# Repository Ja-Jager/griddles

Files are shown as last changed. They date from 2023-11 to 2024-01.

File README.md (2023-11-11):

# ESP-toaster

迁移到 ESP-IDF 平台，增加物联网功能。

死限期：2023 年 2 月 10 日

## 烘包机与炸炉相同功能

| 炸炉 | 烘包机 | 是否能通用 |
| ----- | --- | ----- |
| 温度采集  | 温度采集 | ✔ |
| 继电器 | 继电器 | ✔ |
| 温度判断  | 温度判断 | ✔ |
| 超温保护  | 超温保护 | ✔ |
| 按键 | 按键 | ✔ |
| nvs | nvs | ✔ |
| | 数码管 | ❌ |
| 旋转编码器 | | ❌ |
| 倒计时 | | ❌ |
| | ToF 数面包 | ❌ |

## 完成事项

- [ ] 把当前 Toaster 代码迁移到 Fryer 里
  - [x] 温度采集
  - [x] 继电器
  - [x] 温度判断
  - [x] 超温保护
  - [ ] 按键
- [ ] Fryer 代码
  - [ ] 旋转编码器
  - [x] 倒计时
- [x] 电子板更改设计

## 注意

原本此项是有NTC_thermistor、esp_ntc组件的，但为了队列读取不重复，已经将其压缩放在C盘

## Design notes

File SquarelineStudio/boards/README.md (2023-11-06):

# Custom Boards Usage

The generator supports custom boards. The example of the custom board is [here](https://github.com/espressif/esp-bsp/blob/master/SquareLine/boards/custom_waveshare_7inch). There is custom BSP for the custom board as a component. For use this custom board in SquareLine, follow these steps:

Copy folder from `/espressif/custom_waveshare_7inch` to `"SquareLine Studio installation path"/boards/espressif/`

```
.
├── boards
│   ├── arduino
│   ├── desktop
│   └── espressif
│       ├── custom_waveshare_7inch_v1_0_0
│       │   ├── LICENSE
│       │   ├── custom_waveshare_7inch.png
│       │   ├── custom_waveshare_7inch.slb
│       │   └── custom_waveshare_7inch.zip
│       ├── espbox_v1_0_0
│       └── espwroverkit_v1_0_0

90 directories, 477 files
```

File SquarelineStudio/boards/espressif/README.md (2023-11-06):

# BSP: Custom WaveShare 7inch LCD 

* [Hardware Reference](https://www.waveshare.com/wiki/7inch_Capacitive_Touch_LCD_(C))

This is an example how to make custom BSP and generate custom board for SquareLine Studio.



WaveShare 7inch Capacitive Touch LCD (C) 800x480

* INTERFACE: 8080 series interface
* LCD CONTROLLER: RA8875
* TOUCH CONTROLLER: GT911
* RESOLUTION: 800 * 480 (Pixel)

## Default Hardware Connection

### PARALLEL INTEL 8080 Display

| Display  | ESP32-S3 |
| :---: | :---: |
| CS | **GND**  |
|  RS/DC | GPIO 37  |
| WR | GPIO 38  |
| RD | **3V3**  |
| RST | GPIO 39  |
| PS | **GND**  |
| WAIT |  GPIO 1  |
| D0 | GPIO 13  |
| D1 | GPIO 12  |
| D2 | GPIO 11  |
| D3 | GPIO 10  |
| D4 |  GPIO 9  |
| D5 | GPIO 46  |
| D6 |  GPIO 3  |
| D7 |  GPIO 8  |
| D8 | GPIO 18  |
| D9 | GPIO 17  |
| D10 | GPIO 16  |
| D11 | GPIO 15  |
| D12 |  GPIO 7  |
| D13 |  GPIO 6  |
| D14 |  GPIO 5  |
| D15 |  GPIO 4  |
| D8 ~ D15 | **GND**  |

### I2C Touch

| Display | ESP32-S2 |
| :-----: | :---: |
| SCL | GPIO 41  |
| SDA | GPIO 42  |
| INT |  GPIO 2  |

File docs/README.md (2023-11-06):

# 注意

Header 4 有两个脚接了超温保护。这个电路图没有更新这个事实。

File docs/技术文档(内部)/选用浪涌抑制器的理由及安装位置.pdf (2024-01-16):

# 选用浪涌抑制器的理由及安装位置

选用浪涌抑制器的理由及安装位置
半个扒炉的接线图
具体接线说明
浪涌抑制器
交流接触器
参考实验
实验一
实验二
实验三
实验四
结论
浪涌抑制器的安装位置
结论

## 半个扒炉的接线图

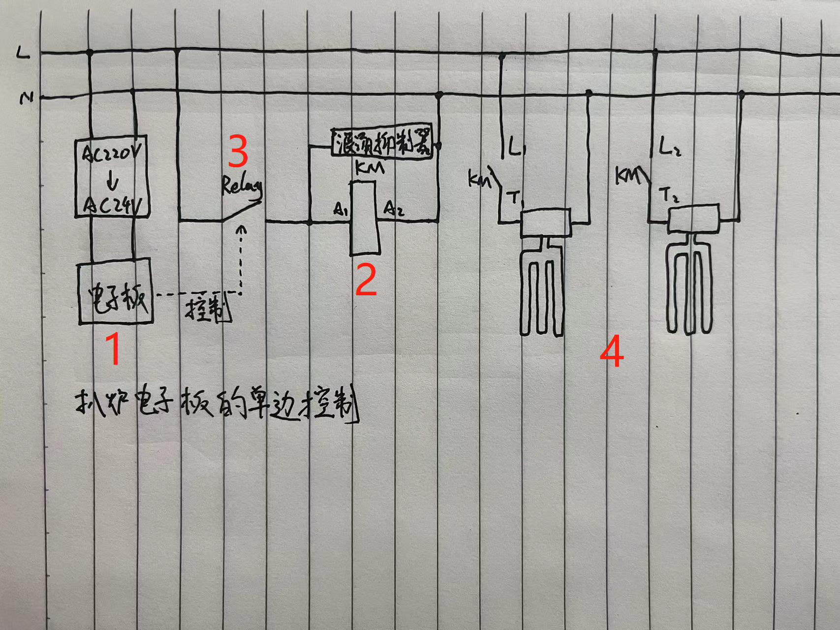
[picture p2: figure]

### 具体接线说明

1. 电子板部分：由一个AC220V转AC24V 80W的变压器供电给电子板。
2. 交流接触器部分：交流接触器控制端有两个引脚A1、A2。

A2直连零线

A1与火线受电子板上的继电器控制导通

A1、A2两端连接浪涌抑制器

3. 电子板继电器控制部分：电子板上的继电器由电子板的硬件设计及加热逻辑所控制。

继电器的控制端由电子板上的24V与达林顿管所控制，只要控制端两端有电压差，继电 器就会吸合

继电器的公共端连接节流接触器的A1脚，常开端连接火线，只要继电器一吸合，交流接 触器的A1脚就等于与火线相连，这样交流接触器就会吸合。

4. 发热管部分：扒炉的一边扒板内部装有两个类似于发热管的加热器件，由交流接触器的输出 端所控制。

交流接触器上除了控制端A1、A2，还有输入端L1、L2、L3、NO，输出端T1、T2、T3、 NO。

输入端L1、L2连接着火线

输出端T1、T2连接着发热管的一端

发热管的另一端直连零线

只要交流继电器吸合，T1、T2等于接通火线，这样发热管就能加热了

## 浪涌抑制器

浪涌抑制器内部主要由电容和电阻的RC电路构成。目的是为了吸收和消耗交流接触器中的电感的 感应电流。

### 交流接触器

在浪涌抑制器的应用之前，先了解交流接触器的组成和造成峰值电流的原因。

1. 交流接触器的组成：交流接触器主要由线圈、衔铁、弹簧、动触点和定触点组成。
2. 交流接触器的工作过程：当交流接触器线圈两端接通火线与零线，线圈就会产生磁场，由楞 次定律，衔铁也会产生磁场，结果线圈与衔铁就吸合在一起。衔铁上连接着动触点，衔铁的 运动使得动触点与常开定触点导通，这样交流接触器就能够正常工作了。
3. 交流接触器的线圈：线圈实际是一段绕成圆筒形的导线，也就是一个电感器件。交流接触器 利用其通电后产生的磁场来控制导通与断开的。但电感最主要的特性还有一个，它能延迟电 流的变化，这会使得线圈在断电后会产生自感电动势。

### 参考实验

可以参考以下博客中所做的实验中的第1至第5点。

继电器线圈泄放电路&&及触点RC吸收电路_接触器线圈吸收电路-CSDN博客 (https://blog.csdn.net/weixin_45633643/article/details/107662100)

这个实验的内容是：通过一个脉冲源控制三极管的通断来模拟继电器（类似接触器）中的线圈的 电压变化；加入反向二极管、RC电路来消除过冲电压。

实验一

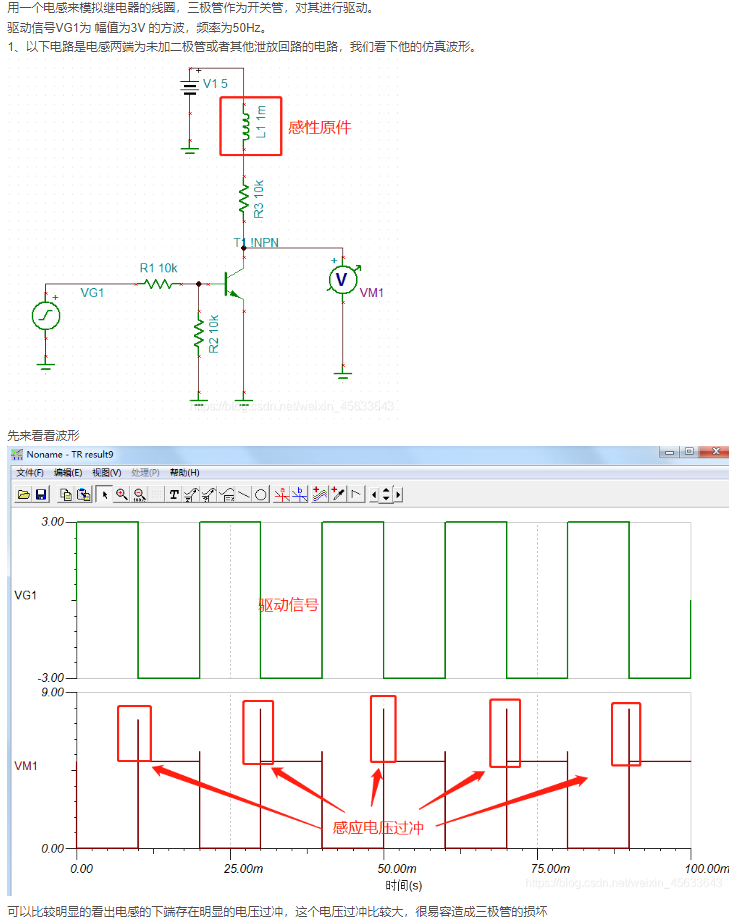
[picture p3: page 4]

实验二

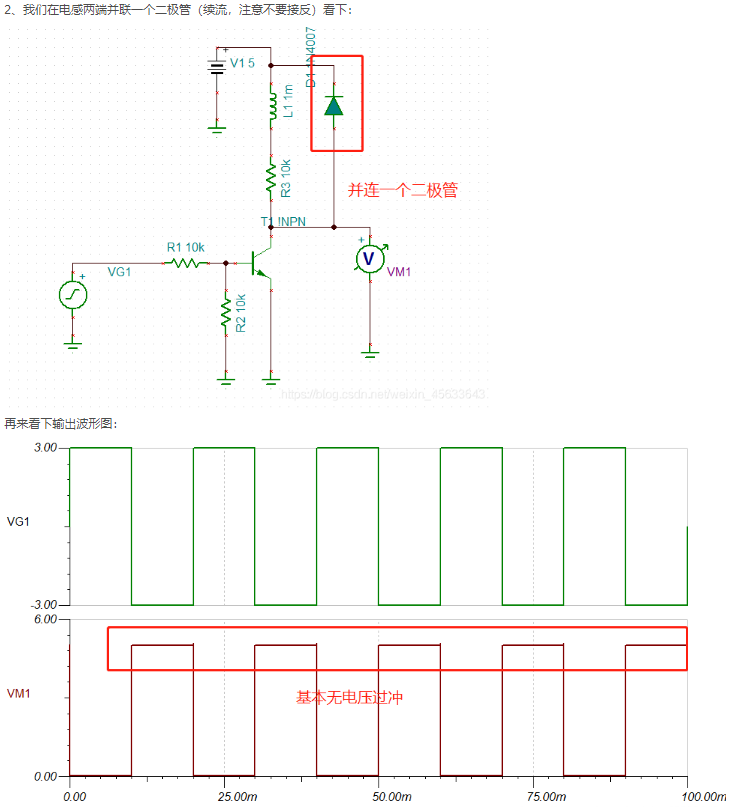
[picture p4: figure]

实验三

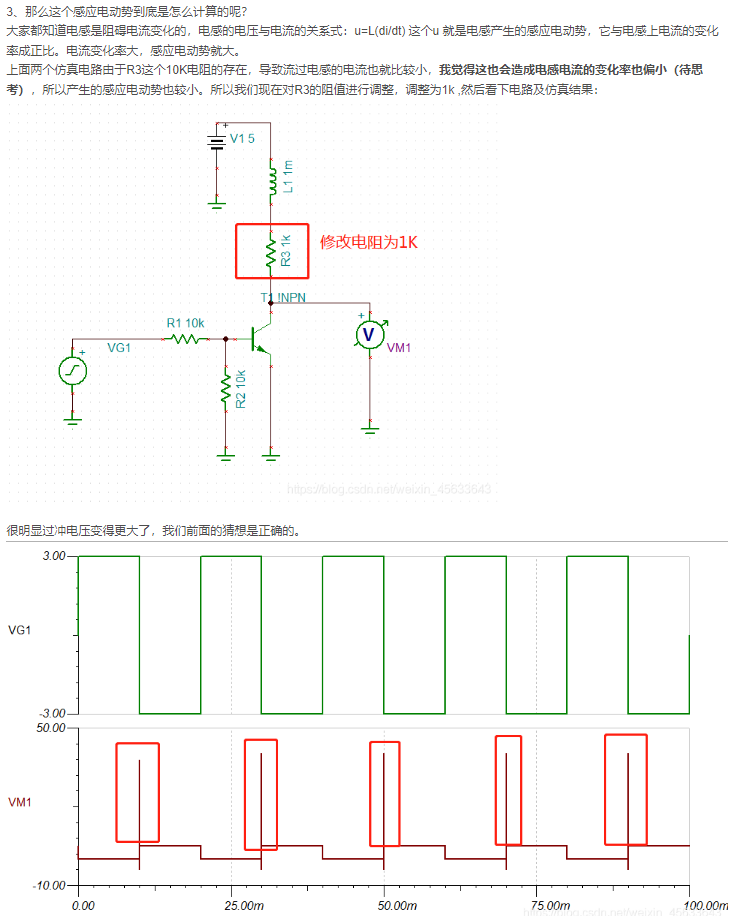
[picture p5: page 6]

实验四

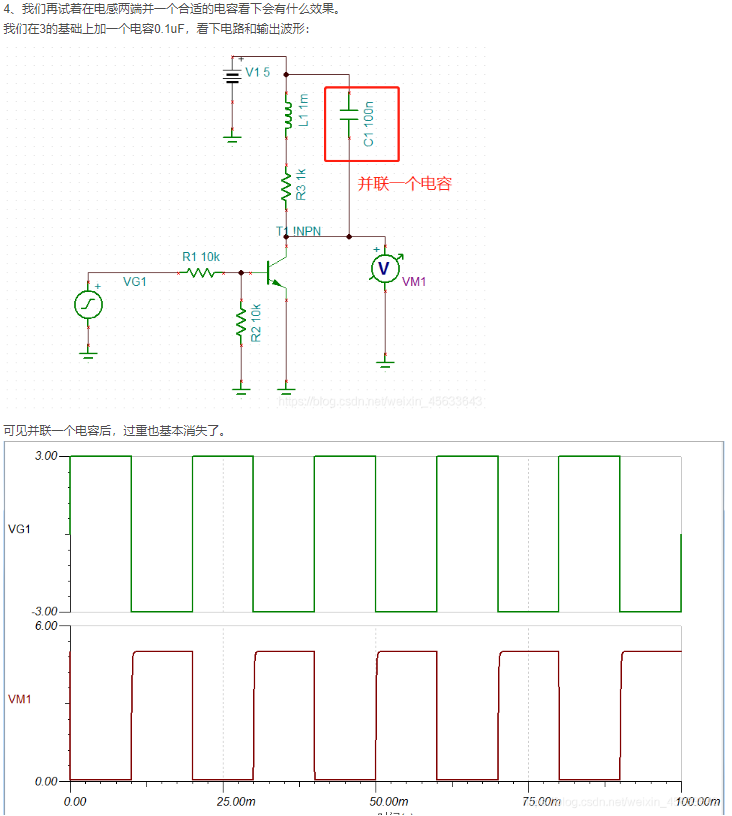
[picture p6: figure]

结论

从以上实验可以看出当电感失去供电后，会出现出现短暂的较大的过冲电压，这对与之相连的电 路会造成较为严重的破坏。

而浪涌抑制器就相当于实验四中加入的电容，可以阻止电压的剧烈变化，再加上个电阻来消耗电 流，故而电路不会再出现电压、电流突然过大的情况。

### 浪涌抑制器的安装位置

浪涌抑制器应安装在交流接触器的线圈两端，也就是A1、A2。
结论

在有线圈需要驱动的强电电路中，安装浪涌抑制器是必要的。

线圈断电后的产生的感应电势、电流会对与之供电相连的其他设备造成破坏，导致一些敏感设备 出现异常。而浪涌抑制器的RC电路能吸收、消耗掉这个感应电势、电流。

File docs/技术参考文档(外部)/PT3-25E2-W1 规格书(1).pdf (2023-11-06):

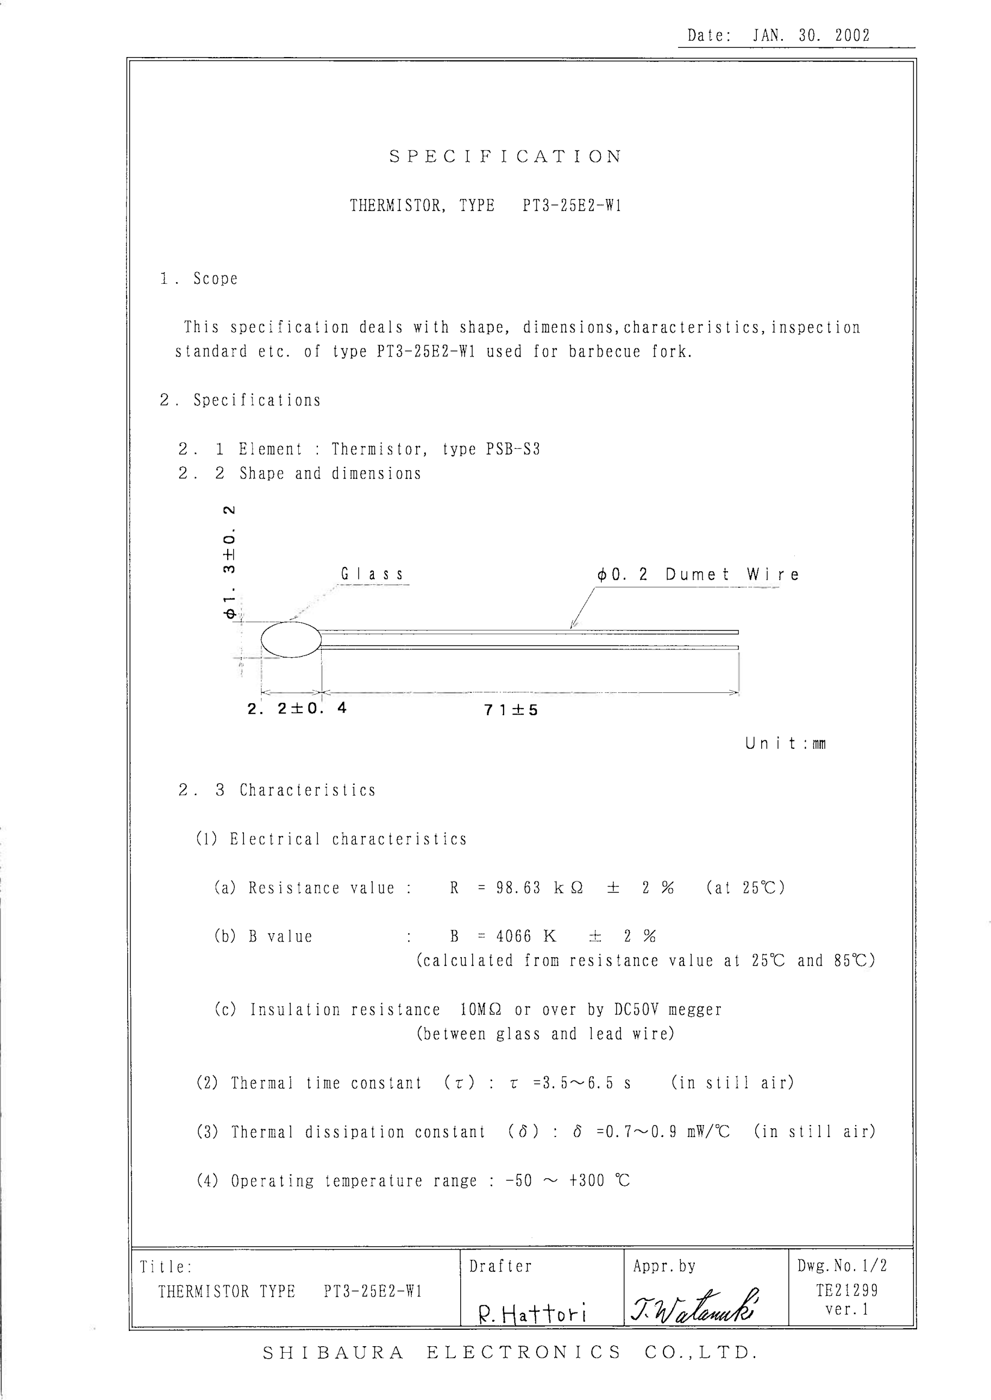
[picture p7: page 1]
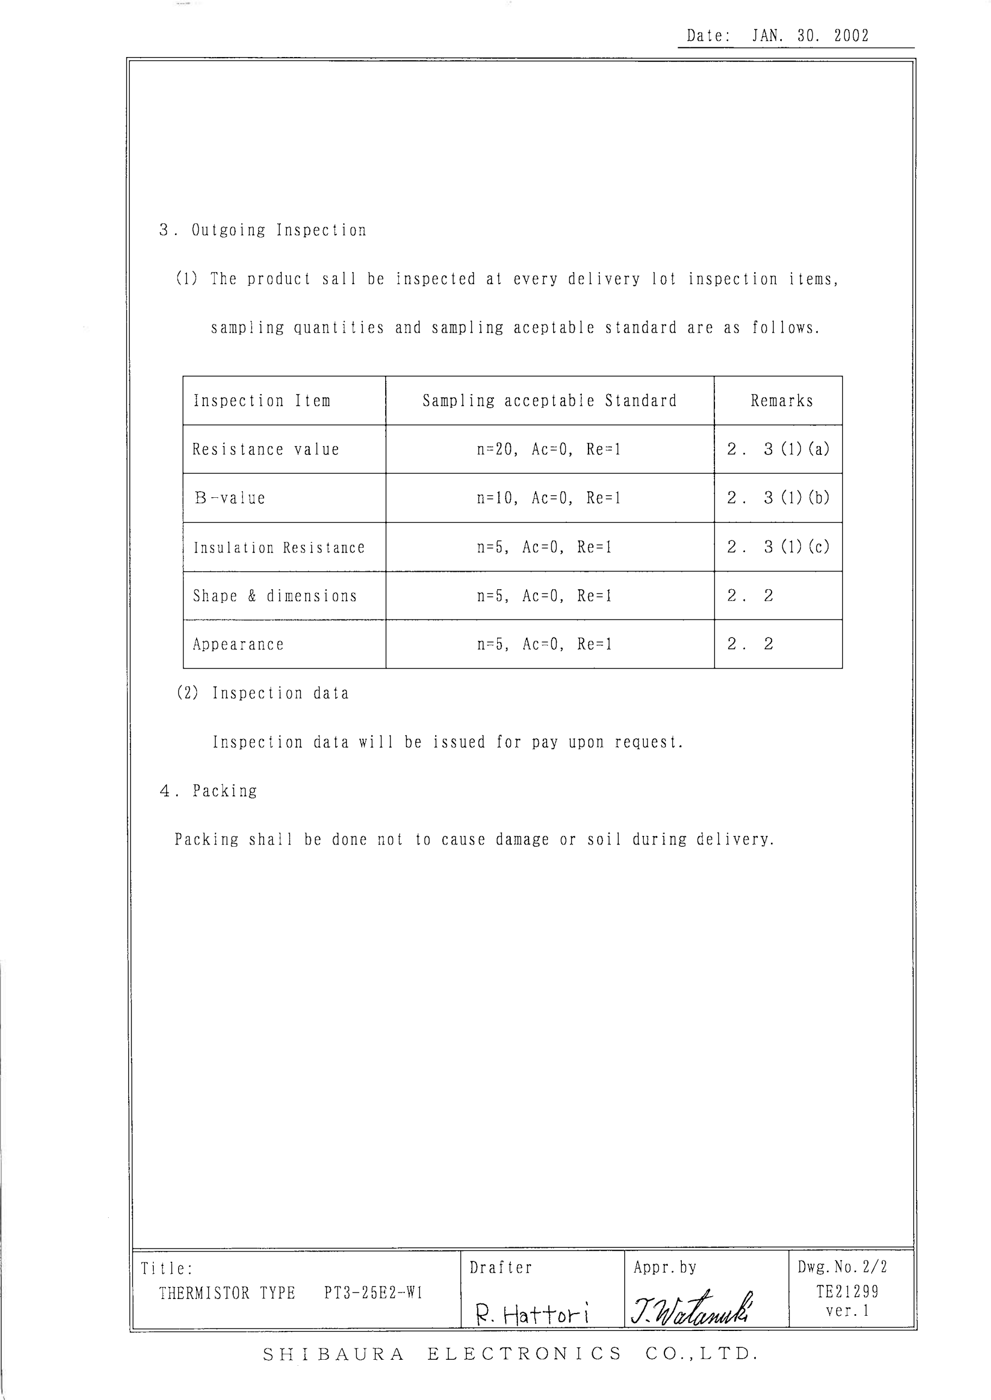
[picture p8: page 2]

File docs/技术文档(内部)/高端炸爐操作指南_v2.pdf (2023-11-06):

# 高端炸爐操作指南

更新时间：2023/9/11 18：00

高端炸爐操作指南
語言切換
使用流程
手動操作
烹飪流程
用戶自定義操作
无倒计时操作
自動操作
烹飪流程
菜單操作
新增菜單
使用流程
編輯菜單
使用流程
刪除菜單
使用流程
溫度單位切換
使用流程
演示模式
使用流程
物理按鍵切換操作頁面
超溫保護、泄油、發熱管擡起

# 語言切換

1. 用戶通過左邊的橫欄【手动】、【计时】、【设置】，按下【设置】以選擇設置。
2. 滑動如下圖的語言切換滾輪。

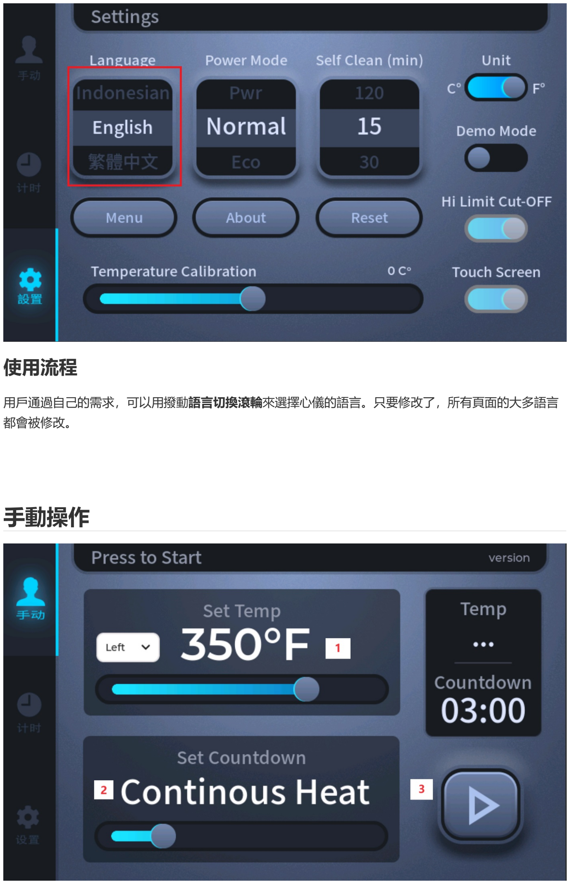
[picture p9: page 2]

## 使用流程

用戶通過自己的需求，可以用撥動語言切換滾輪來選擇心儀的語言。只要修改了，所有頁面的大多語言 都會被修改。

# 手動操作

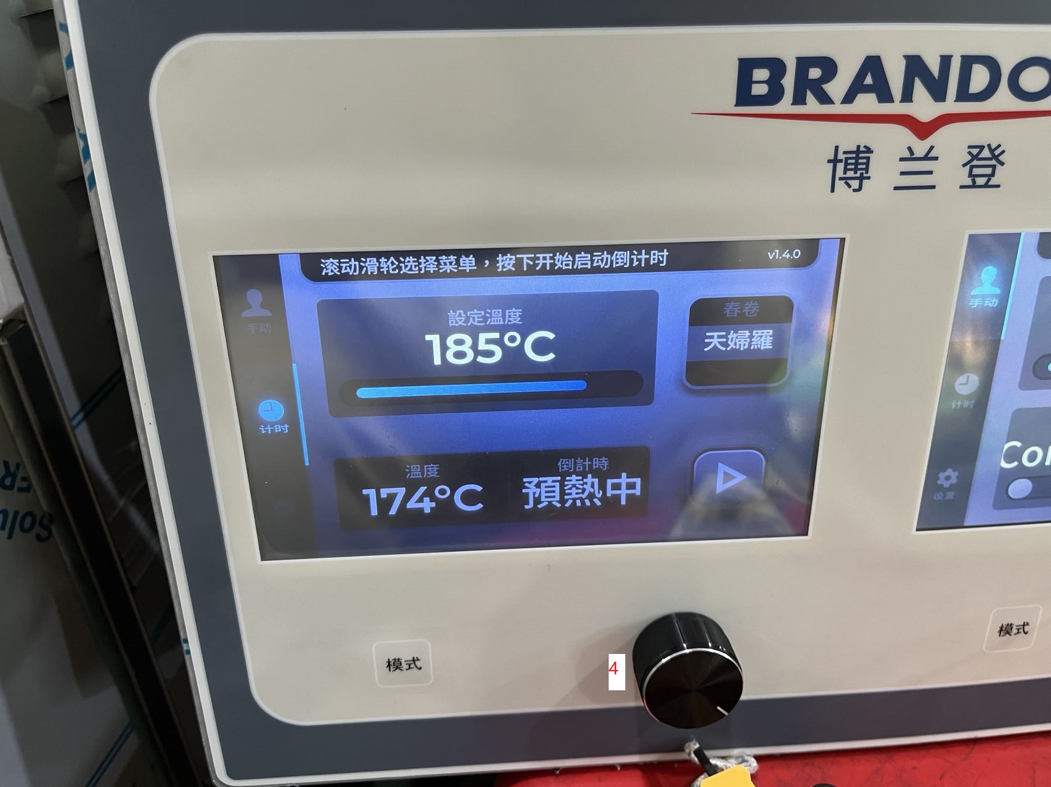
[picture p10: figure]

手動操作可以操作的位置有如上圖的4個位置。

1. 設定溫度滑條（量程：100℃ ~ 200℃，200℉ ~ 400℉）
2. 設定倒計時滑條（量程：15min，滑動的最小一格為10s）
3. 開始鍵
4. 旋鈕及旋鈕按鍵

## 烹飪流程

### 用戶自定義操作

1. 用戶通過左邊的橫欄【手动】、【计时】、【设置】，按下【手动】以選擇手動模式。
2. 用戶通過自己的需求，可以用滑條或旋鈕調整設定溫度。（建議：滑條用於大幅度調整，旋鈕用於 微小調整）。
3. 用戶通過自己的需求，可以用滑條調整設定倒計時。
4. 按下開始鍵或旋鈕，機器就會開啓加熱。
5. 按下開始鍵后，當溫度還未到達設定溫度時，【倒計時】下會顯示【預熱中】。
6. 當溫度達到設定溫度時，會出現一個頁面，提示投放食物。投放完食物后，按下屏幕上的 【DONE】，倒計時開啓。
7. 當倒計時結束或客戶再次按下開始鍵或旋鈕按鍵，機器就會結束倒計時，停止加熱。

### 无倒计时操作

1. 用戶通過自己的需求，可以用滑條或旋鈕調整設定溫度。（建議：滑條用於大幅度調整，旋鈕用於 微小調整）。
2. 當溫度滑條拉至最左端，此時【設定倒計時】下會顯示【持續運行】。
3. 按下開始鍵或旋鈕，機器就會開啓加熱。
4. 按下開始鍵后，當溫度還未到達設定溫度時，【倒計時】下會顯示【預熱中】。
5. 當溫度達到設定溫度時，會出現一個頁面，提示投放食物。投放完食物后，按下屏幕上的 【DONE】。

# 自動操作

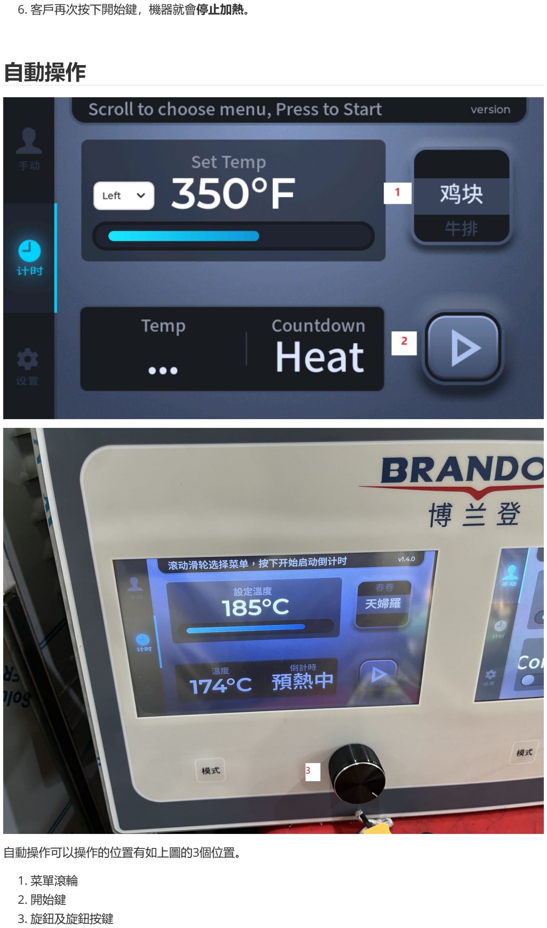
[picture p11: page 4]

6. 客戶再次按下開始鍵，機器就會停止加熱。

自動操作可以操作的位置有如上圖的3個位置。

1. 菜單滾輪
2. 開始鍵
3. 旋鈕及旋鈕按鍵

## 烹飪流程

1. 用戶通過左邊的橫欄【手动】、【计时】、【设置】，按下【自动】以選擇自動模式。
2. 用戶通過自己的需求，可以用滾輪或旋鈕選擇自己想要的菜單。
3. 按下開始鍵或旋鈕，機器就會開啓加熱。
4. 按下開始鍵后，當溫度還未到達設定溫度時，【倒計時】下會顯示【預熱中】。
5. 當溫度達到設定溫度時，會出現一個頁面，提示投放食物。投放完食物后，按下屏幕上的 【DONE】，倒計時開啓。
6. 客戶再次按下開始鍵，機器就會停止加熱。
7. 當用戶用自動模式開啓加熱時，如果沒有切換界面，按下任何物理按鍵、開始鍵和滑動滾輪，就會 彈出一個屏保頁面，類似與下圖。顯示的内容：倒計時、菜單名。

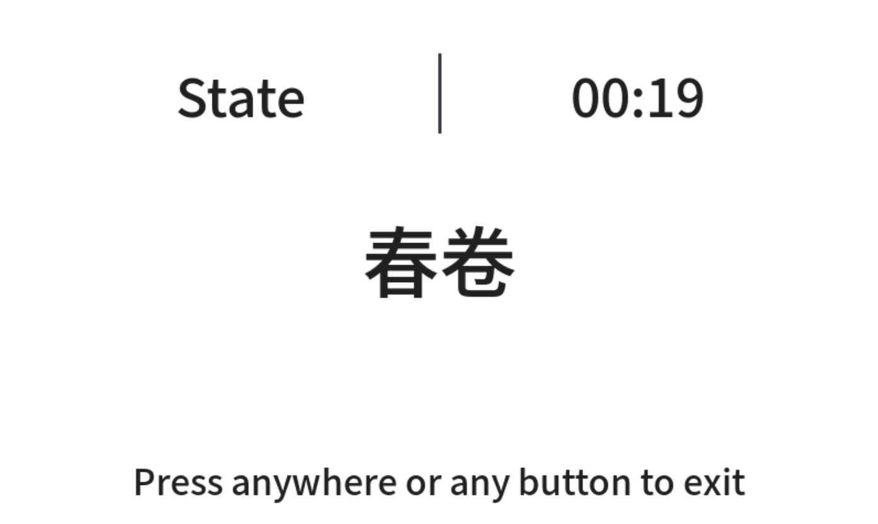
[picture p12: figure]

# 菜單操作

1. 用戶通過左邊的橫欄【手动】、【计时】、【设置】，按下【设置】以選擇設置。
2. 點擊如下圖的【menu】。

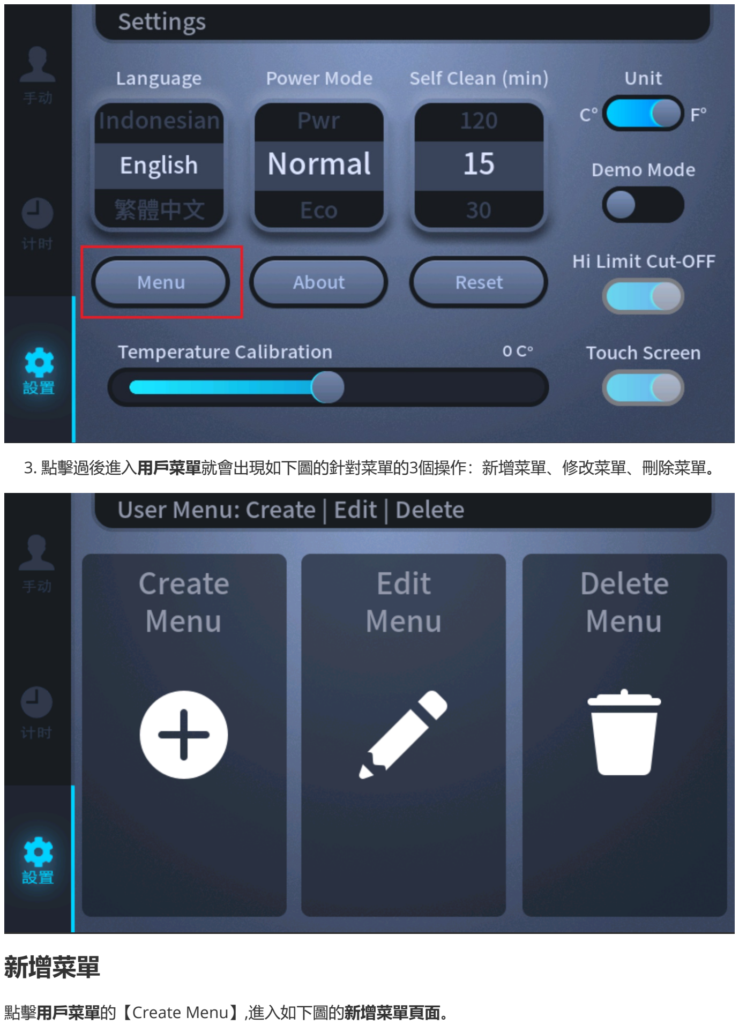
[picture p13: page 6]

3. 點擊過後進入用戶菜單就會出現如下圖的針對菜單的3個操作：新增菜單、修改菜單、刪除菜單。

## 新增菜單

點擊用戶菜單的【Create Menu】,進入如下圖的新增菜單頁面。

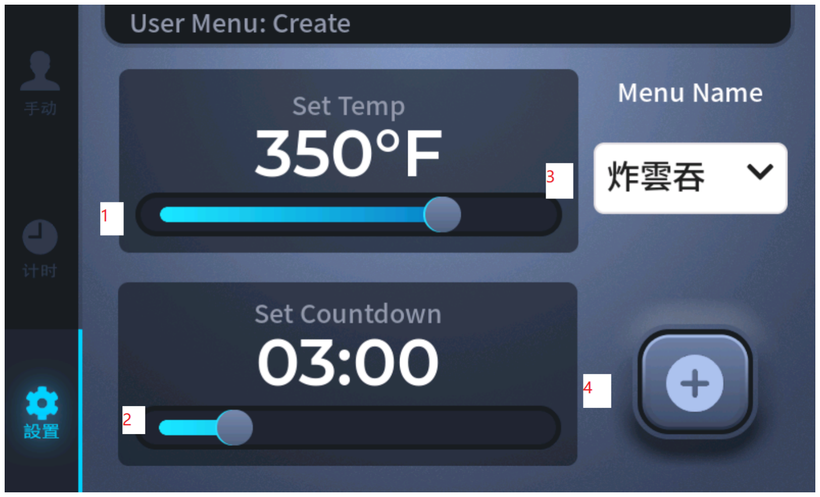
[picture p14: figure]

新增菜單可以操作的位置有如上圖的4個位置。

1. 設定溫度滑條（量程：100℃ ~ 200℃，200℉ ~ 400℉）
2. 設定倒計時滑條（量程：15min，滑動的最小一格為10s）
3. 菜單列表
4. 新增菜單鍵

### 使用流程

1. 用戶通過自己的需求，可以用滑條調整設定溫度。
2. 用戶通過自己的需求，可以用滑條調整設定倒計時。
3. 用戶通過自己的需求，可以用下拉式列表選擇心儀的菜單名。
4. 用戶確定完自己的選擇後，通過按下新增菜單鍵來新增菜單，新增的菜單出現將在自動操作的滾輪 選項中。

## 編輯菜單

點擊用戶菜單的【Edit Menu】,進入如下圖的編輯菜單頁面1。

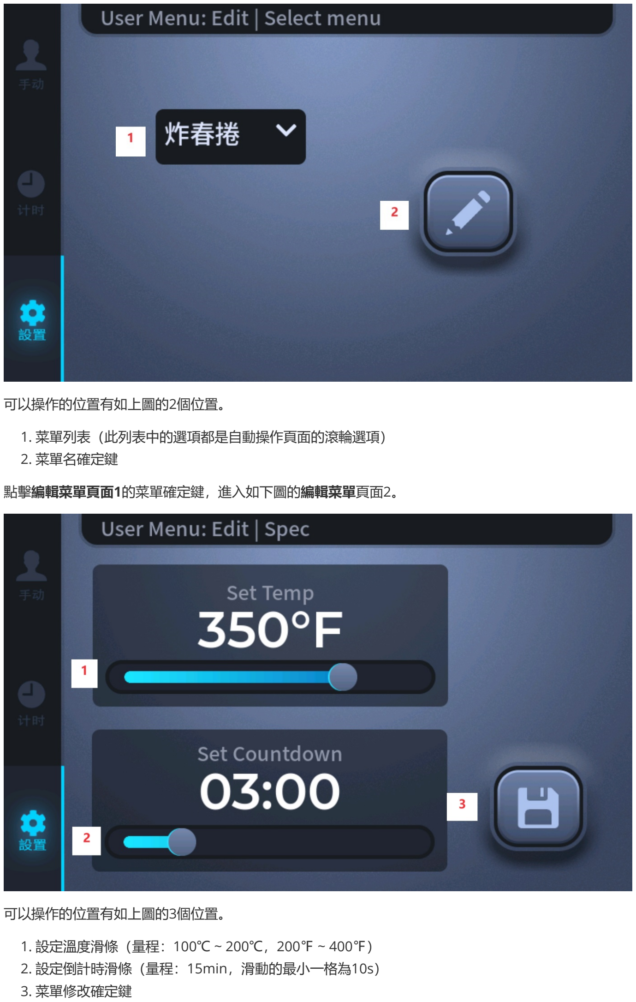
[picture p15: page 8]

可以操作的位置有如上圖的2個位置。

1. 菜單列表（此列表中的選項都是自動操作頁面的滾輪選項）
2. 菜單名確定鍵

點擊編輯菜單頁面1的菜單確定鍵，進入如下圖的編輯菜單頁面2。

可以操作的位置有如上圖的3個位置。

1. 設定溫度滑條（量程：100℃ ~ 200℃，200℉ ~ 400℉）
2. 設定倒計時滑條（量程：15min，滑動的最小一格為10s）
3. 菜單修改確定鍵

### 使用流程

1. 用戶通過自己的需求，可以用菜單列表選擇需要修改的自動操作頁面的菜單選項。
2. 按下菜單名確定鍵，進入編輯菜單頁面2。
3. 進入編輯菜單頁面2后，用戶通過自己的需求，可以用滑條修改設定溫度。
4. 用戶通過自己的需求，可以用滑條修改設定倒計時。
5. 用戶確定完自己的要修改的選擇後，通過按下菜單修改確定鍵來修改菜單，修改后的菜單會更新到 自動操作的滾輪選項中。

## 刪除菜單

點擊用戶菜單的【Delete Menu】,進入如下圖的刪除菜單頁面。

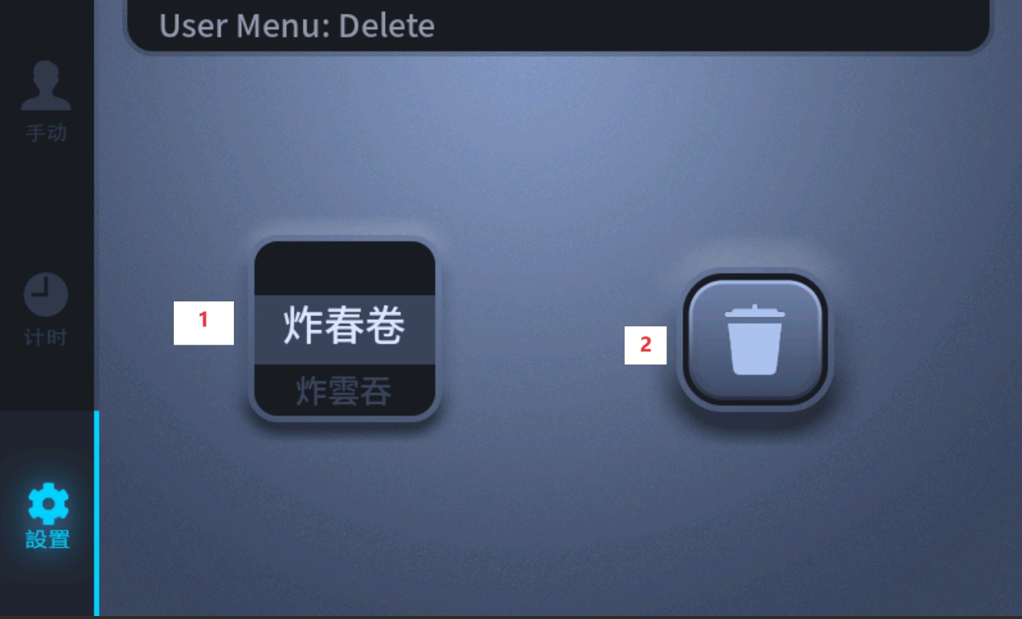
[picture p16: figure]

可以操作的位置有如上圖的2個位置。

1. 菜單名滾輪（此列表中的選項都是自動操作頁面的滾輪選項）
2. 菜單刪除確定鍵

### 使用流程

1. 用戶通過自己的需求，可以用菜單名滾輪選擇需要刪除的自動操作頁面的菜單選項。
2. 用戶確定完自己的要刪除的選擇後，通過按下菜單刪除確定鍵來刪除菜單，刪除后，菜單會更新到 自動操作的滾輪選項中。

# 溫度單位切換

1. 用戶通過左邊的橫欄【手动】、【计时】、【设置】，按下【设置】以選擇設置。
2. 點擊如下圖的溫度單位切換開關。

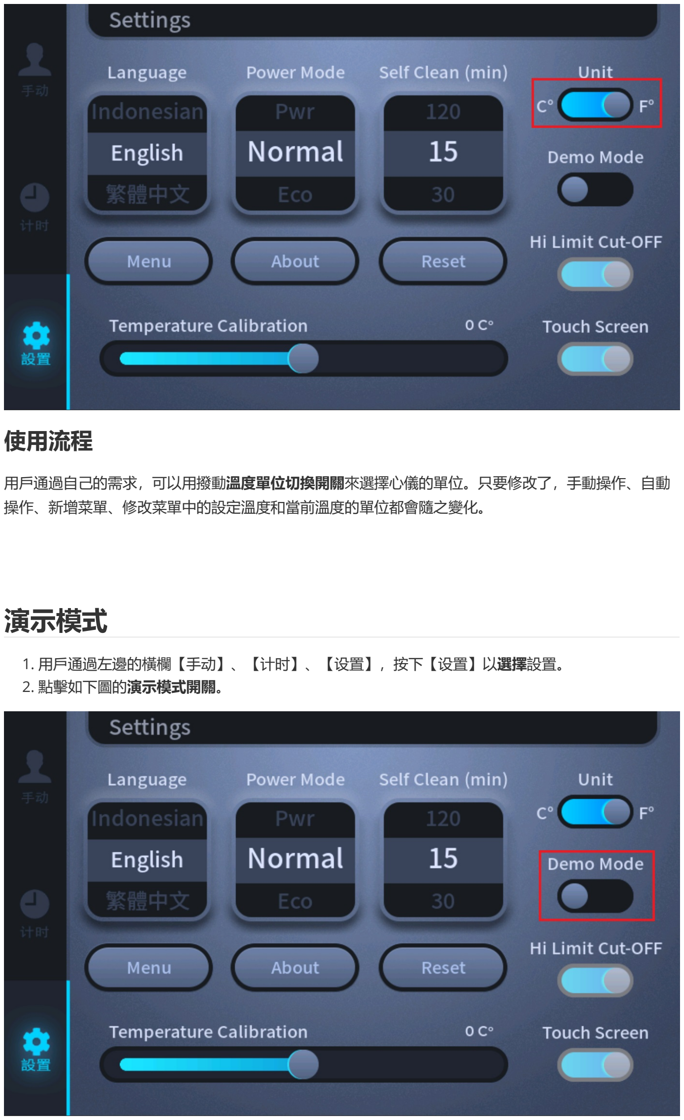
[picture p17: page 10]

## 使用流程

用戶通過自己的需求，可以用撥動溫度單位切換開關來選擇心儀的單位。只要修改了，手動操作、自動 操作、新增菜單、修改菜單中的設定溫度和當前溫度的單位都會隨之變化。

# 演示模式

1. 用戶通過左邊的橫欄【手动】、【计时】、【设置】，按下【设置】以選擇設置。
2. 點擊如下圖的演示模式開關。

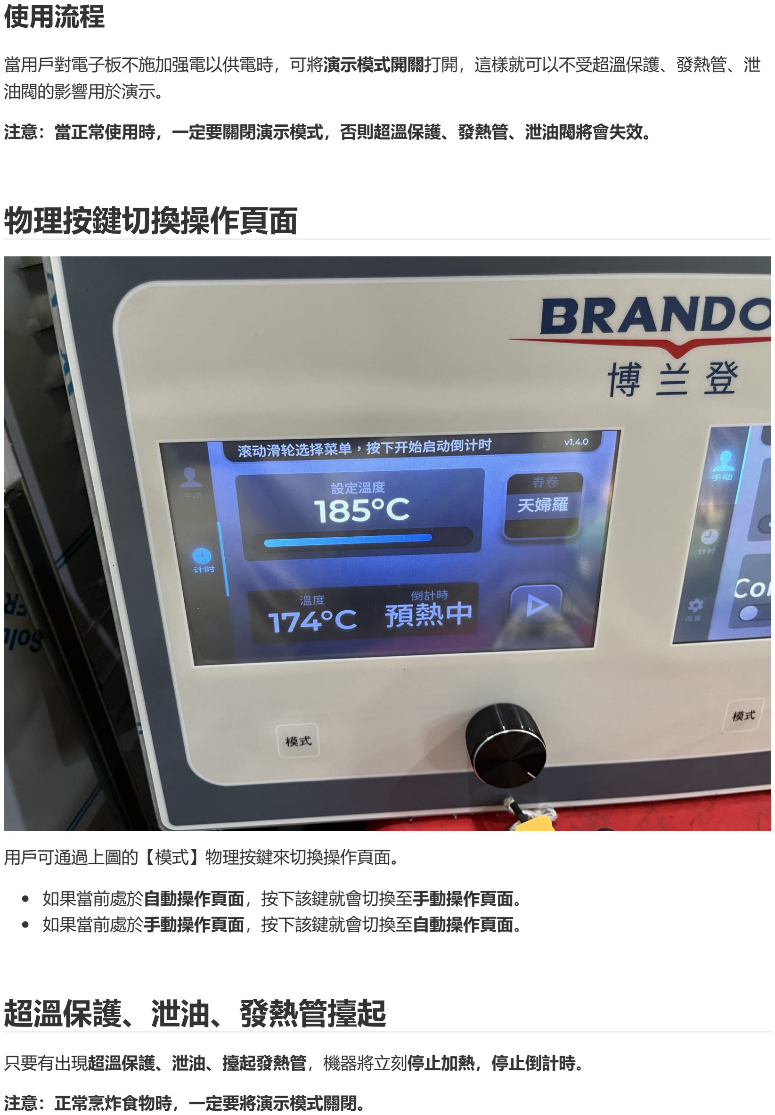
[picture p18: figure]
使用流程; 當用戶對電子板不施加强電以供電時，可將演示模式開關打開，這樣就可以不受超溫保護、發熱管、泄 油閥的影響用於演示。; 注意：當正常使用時，一定要關閉演示模式，否則超溫保護、發熱管、泄油閥將會失效。; 物理按鍵切換操作頁面; 用戶可通過上圖的【模式】物理按鍵來切換操作頁面。; 如果當前處於自動操作頁面，按下該鍵就會切換至手動操作頁面。 如果當前處於手動操作頁面，按下該鍵就會切換至自動操作頁面。; 超溫保護、泄油、發熱管擡起; 只要有出現超溫保護、泄油、擡起發熱管，機器將立刻停止加熱，停止倒計時。; 注意：正常烹炸食物時，一定要將演示模式關閉。

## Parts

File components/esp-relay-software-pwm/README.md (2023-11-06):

# ESP-RELAY-SOFTWARE-PWM

1. 声明一个结构体配置初始化参数并初始化

``` c
softPwm_t softpwm=
{
    .PWMPin = 19,
    .freq = 0.2,
};

```

2. 调用 softpwm_init(&softpwm)

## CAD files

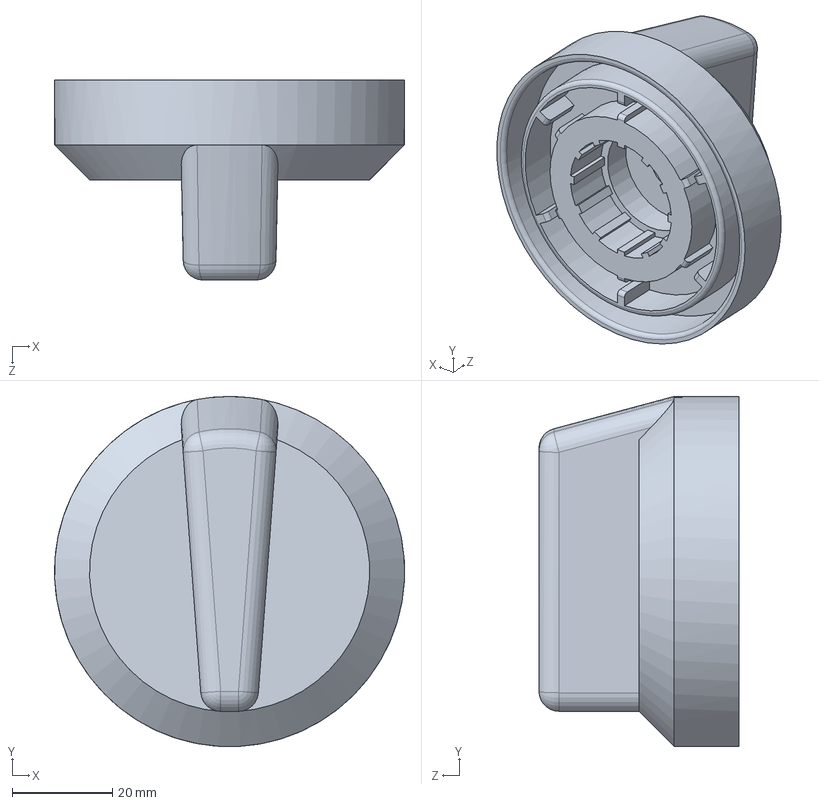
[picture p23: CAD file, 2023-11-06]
docs/技术文档(内部)/旋钮7.0.SLDPRT
70.0 x 70.0 x 40.0 mm

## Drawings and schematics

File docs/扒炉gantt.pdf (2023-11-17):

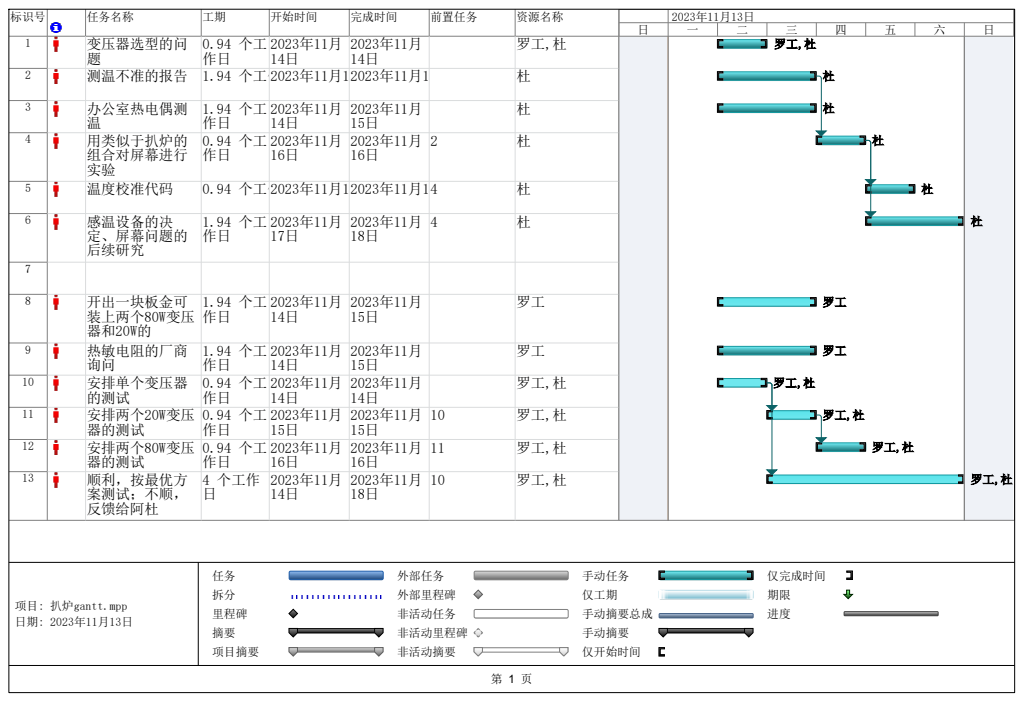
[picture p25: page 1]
标识号; 任务名称; 开始时间; 完成时间; 前置任务; 资源名称; 变压器选型的问; 测温不准的报告; 1.94 个工作日2023年11月14日2023年11月15日; 办公室热电偶测; 用类似于扒炉的; 组合对屏幕进行 实验; 温度校准代码; 0.94 个工作日2023年11月17日2023年11月17日4; 感温设备的决; 定、屏幕问题的 后续研究; 开出一块板金可; 装上两个80W变压 器和20W的; 热敏电阻的厂商; 安排单个变压器; 的测试; 安排两个20W变压; 器的测试; 安排两个80W变压; 顺利，按最优方; 案测试；不顺， 反馈给阿杜; 4 个工作 日; 里程碑; 项目摘要; 外部任务; 外部里程碑; 非活动任务; 非活动里程碑; 非活动摘要; 手动任务; 仅工期; 手动摘要总成; 手动摘要; 仅开始时间; 仅完成时间

项目: 扒炉gantt.mpp

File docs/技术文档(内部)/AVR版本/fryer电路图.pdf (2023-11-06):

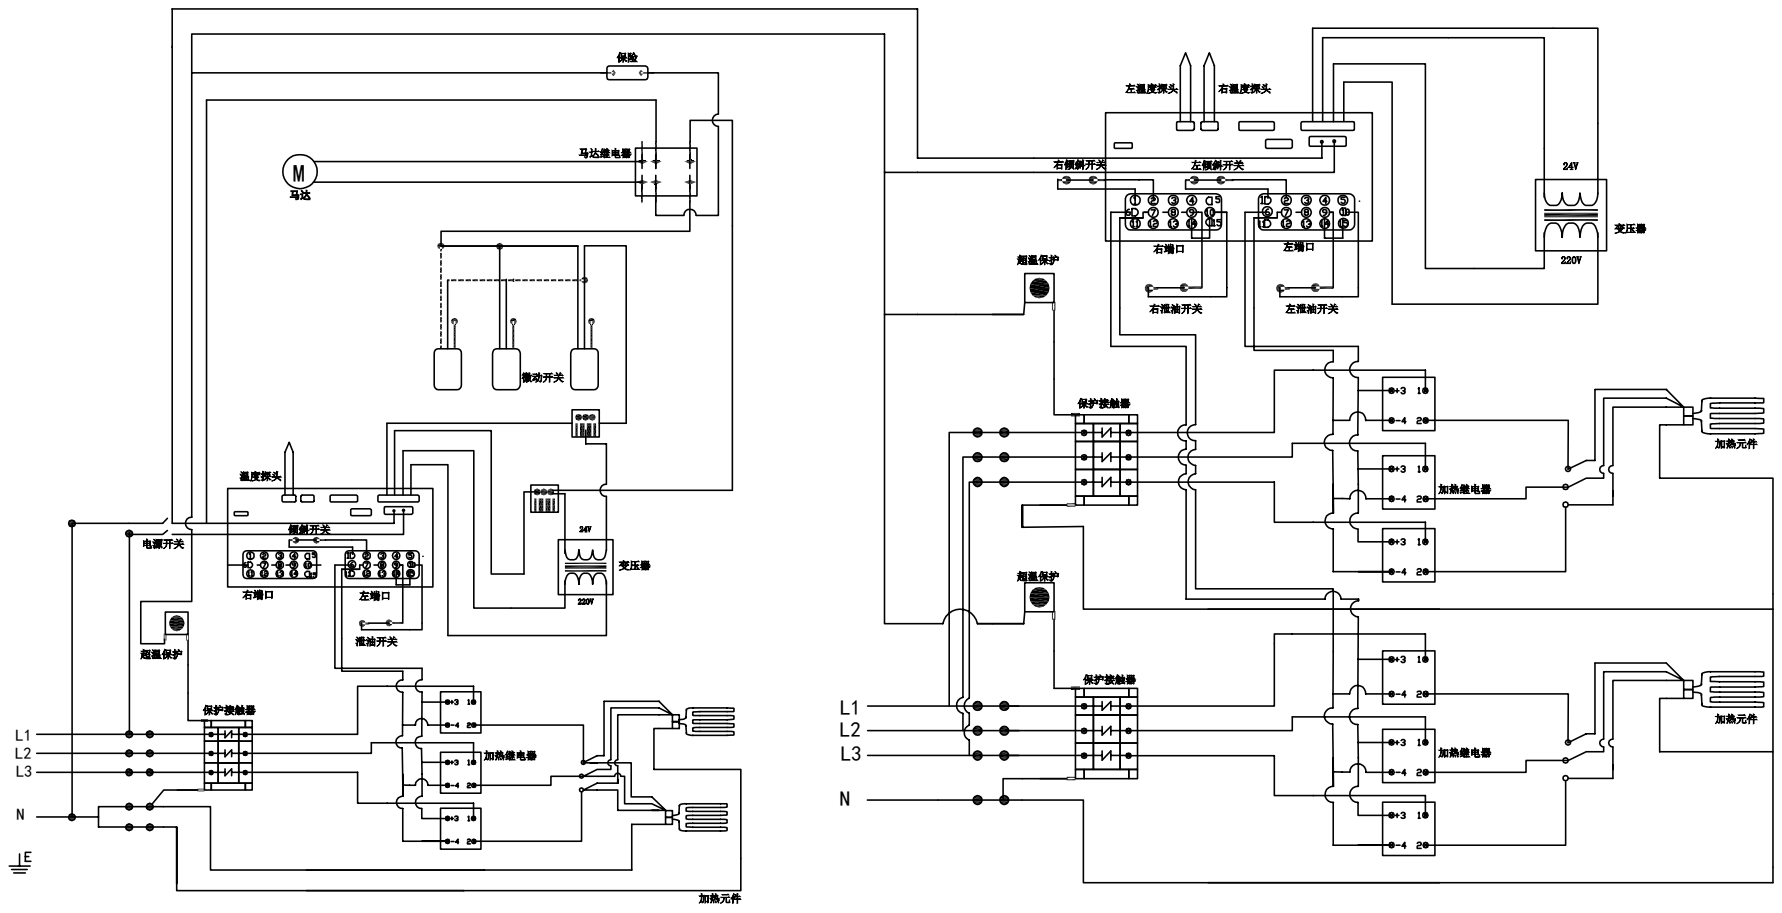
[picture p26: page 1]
泄油开关; 倾斜开关; 右端口; 保护接触器; 电源开关; 加热元件; 加热继电器; 马达继电器; 温度探头; 变压器; 超温保护; 微动开关; 左端口; 右倾斜开关; 左倾斜开关; 右泄油开关; 左泄油开关; 左温度探头; 右温度探头

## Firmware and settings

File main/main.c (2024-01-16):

#include "main.h"

#define TAG "ESP-EXAMPLE"

#define Manual_Temperature_Fahrenheit_Maximum 464
#define Manual_Temperature_Fahrenheit_Minimum 212

#define Manual_Temperature_Celsius_Maximum 240
#define Manual_Temperature_Celsius_Minimum 100

#define Temperature_Unit_Fahrenheit_for_main 1
#define Temperature_Unit_Celsius_for_main 0

#define Time_Needed_appear_ScreenSaver 30

lv_obj_t *label;

bool temperature_unit_main = Temperature_Unit_Fahrenheit_for_main;

screen_is_loaded_t current_screen_load = No_loaded;
// TaskHandle_t * handle_UI_Task;

/*******************************************************************************
 * Private functions
 *******************************************************************************/
void UI_task(void *pvParameters)
{
    // 上电读取NVS，修改语言
    set_language_by_nvs_for_power_on();

    // 自动操作初始化显示
    food_menu_item_config temporary_menu = menu_search_by_sequence(0); // 选择默认鸡块菜单
    double TargetTemperature = 450;

    // lv_obj_add_flag(ui_DropdownMotorLeftRightAuto, LV_OBJ_FLAG_HIDDEN);     /// Flags
    // lv_obj_add_flag(ui_DropdownMotorLeftRightManual, LV_OBJ_FLAG_HIDDEN);     /// Flags

    if (temperature_unit == Temperature_Unit_Fahrenheit)
    {
        Encoder_temperature_queue_write(((TargetTemperature - 273.15) * 1.80 + 32.00));
    }
    else
    {
        Encoder_temperature_queue_write((TargetTemperature - 273.15));
    }
    int32_t current_encoder = 0;
    int32_t previous_encoder = 0;

    // 显示初始化自動操作倒计时
    lv_label_set_text_fmt(ui_LabelSetTimeValue, _("%d:%d"), temporary_menu.cooking_timer_seconds / 60, temporary_menu.cooking_timer_seconds % 60); // 显示初始设定时间

    // 显示初始化手動操作倒计时
    lv_label_set_text_fmt(ui_LabelSensorTempValue2, "%s", _("03:00"));

    // 显示初始化手動操作设定时间
    lv_label_set_text(ui_LabelManualTimerSet, "03:00");

    // 显示初始化温度
    if (temperature_unit == Temperature_Unit_Fahrenheit_for_main)
    {
        lv_label_set_text_fmt(ui_LabelTargetTemperatureValue, "%d°F", (int32_t)(round)((temporary_menu.target_temperature - 273.15) * 1.80 + 32.00)); // 显示初始设定温度
    }
    else
    {
        lv_label_set_text_fmt(ui_LabelTargetTemperatureValue, "%d°C", (int32_t)(round)(temporary_menu.target_temperature - 273.15)); // 显示初始设定温度
    }

    // 显示版本号
    lv_label_set_text_fmt(ui_LabelHeaderVersionNumber, "%s", VERSION_NUMBER);
    lv_label_set_text_fmt(ui_LabelHeaderVersionNumber1, "%s", VERSION_NUMBER);

    /* 提取menu_config_json_str菜单名并写入 */
    cJSON *menu_config_json;
    menu_config_json = cJSON_Parse(menu_config_json_str_return());

    cJSON *food_menu = cJSON_GetObjectItemCaseSensitive(menu_config_json, "food_menu");
    int array_size = cJSON_GetArraySize(food_menu);

    char menu_roller_new_option_name[500] = "";
    for (int i = 0; i < array_size; i++)
    {
        cJSON *food = cJSON_GetArrayItem(food_menu, i);
        cJSON *food_name = cJSON_GetObjectItemCaseSensitive(food, "name");
        if (i == 0)
        {
            strcpy(menu_roller_new_option_name, food_name->valuestring);
        }
        else
        {
            strcat(menu_roller_new_option_name, "\n");
            strcat(menu_roller_new_option_name, food_name->valuestring);
        }
    }
    cJSON_Delete(menu_config_json);
    lv_roller_set_options(ui_MenuOptionRollerChoose, menu_roller_new_option_name, LV_ROLLER_MODE_NORMAL);
    lv_roller_set_options(ui_RollerDeleteMenuChoose, menu_roller_new_option_name, LV_ROLLER_MODE_NORMAL);
    lv_dropdown_set_options(ui_DropdownEditMenuChoose, menu_roller_new_option_name);
    /* Create a task for NTC thermistor */
    lv_timer_t *timer_thermistor_update = lv_timer_create(NTC_thermistor_update_UI, 100, NULL);

    /* Create a task for manual countdown */
    lv_timer_t *manual_countdown_update = lv_timer_create(manual_mode_countdown_update_UI, 100, NULL);

    /* 当前屏幕 */
    lv_obj_t *active_screen;
    uint16_t MenuRollerChooseSelectedOption = 0;

    // printf("Calibration: %d\n", NTC_thermistor_calibration_queue_read());
    lv_label_set_text_fmt(ui_Label_Print_Speed_Number, "%d K", NTC_thermistor_calibration_queue_read());
    lv_slider_set_value(ui_Slider_Print_Speed, NTC_thermistor_calibration_queue_read(), LV_ANIM_OFF);

    lv_obj_add_event_cb(ui_ScreenAuto, my_ScreenAuto_cb, LV_EVENT_ALL, NULL);
    lv_obj_add_event_cb(ui_ScreenManual, my_ScreenManual_cb, LV_EVENT_ALL, NULL);
    lv_obj_add_event_cb(ui_ScreenSetting, my_ScreenSetting_cb, LV_EVENT_ALL, NULL);
    while (1) 
    {     
        // Manual Mode
        // 手动操作倒计时剩余时间显示
        enum mode_select_state current_PID_mode = PID_mode_read();

        lv_label_set_text(ui_LabelAutoHeader, "Scroll to choose menu, Press to Start");//"滚动滑轮选择菜单，按下开始键启动倒计时"
        lv_label_set_text(ui_LabelAutoHeader1, "Press Start to turn on cooking.");//"按下开始键保持恒温"

        // 手动操作温度显示（旋钮）
        current_encoder = Encoder_queue_read();
        TargetTemperature = Encoder_temperature_queue_read();
        //获取屏幕名称
        
        if (current_encoder != previous_encoder)
        {
            active_screen = lv_scr_act();
            if((active_screen == ui_ScreenAuto) || (active_screen == ui_ScreenScreenSaverMenu))
            {
                if(lv_roller_get_selected(ui_MenuOptionRollerChoose) == 0)
                {
                    if((current_encoder - previous_encoder) < 0)
                    {
                        MenuRollerChooseSelectedOption = 0;
                    }
                    else
                    {
                        MenuRollerChooseSelectedOption = lv_roller_get_selected(ui_MenuOptionRollerChoose) + (current_encoder - previous_encoder);
                    }
                }
                else
                {
                    MenuRollerChooseSelectedOption = lv_roller_get_selected(ui_MenuOptionRollerChoose) + (current_encoder - previous_encoder);
                }
                lv_roller_set_selected(ui_MenuOptionRollerChoose, MenuRollerChooseSelectedOption, LV_ANIM_ON);
                vTaskDelay(1 / portTICK_PERIOD_MS);
                lv_event_send(ui_MenuOptionRollerChoose, LV_EVENT_VALUE_CHANGED, NULL);
            }
            else if(active_screen == ui_ScreenManual)
            {
                TargetTemperature = TargetTemperature + (double)(current_encoder - previous_encoder);
                if (temperature_unit == Temperature_Unit_Fahrenheit_for_main)
                {
                    if (TargetTemperature >= Manual_Temperature_Fahrenheit_Maximum)
                    {
                        TargetTemperature = Manual_Temperature_Fahrenheit_Maximum;
                    }
                    else if (TargetTemperature <= Manual_Temperature_Fahrenheit_Minimum)
                    {
                        TargetTemperature = Manual_Temperature_Fahrenheit_Minimum;
                    }
                }
                else
                {
                    if (TargetTemperature >= Manual_Temperature_Celsius_Maximum)
                    {
                        TargetTemperature = Manual_Temperature_Celsius_Maximum;
                    }
                    else if (TargetTemperature <= Manual_Temperature_Celsius_Minimum)
                    {
                        TargetTemperature = Manual_Temperature_Celsius_Minimum;
                    }
                }
            }  
        }
        // printf("TargetTemperature:\n%f\n", TargetTemperature);
        if (temperature_unit == Temperature_Unit_Fahrenheit_for_main)
        {
            lv_label_set_text_fmt(ui_LabelManualTargetTemperature, "%d°F", (int32_t)TargetTemperature);
        }
        else
        {
            lv_label_set_text_fmt(ui_LabelManualTargetTemperature, "%d°C", (int32_t)TargetTemperature);
        }
        lv_slider_set_value(ui_SliderManualTargetTemperature, (int32_t)TargetTemperature, LV_ANIM_ON);

        Encoder_temperature_queue_write(TargetTemperature);
        previous_encoder = current_encoder;

        if (current_PID_mode == mode_manual)
        {
            if (temperature_unit == Temperature_Unit_Fahrenheit_for_main)
            {
                PID_set_temperature_write((TargetTemperature - 32.00) / 1.800 + 273.15); // 发送手动操作设定温度给PID
            }
            else
            {
                PID_set_temperature_write(TargetTemperature + 273.15); // 发送手动操作设定温度给PID
            }
        }
        // printf("current_PID_mode:%d\n", current_PID_mode);
        vTaskDelay(150 / portTICK_PERIOD_MS);
    }
}

// *INDENT-OFF*
void app_lvgl_display(void)
{
    bsp_display_lock(0);

#ifdef LVGL_BENCHMARK
    lv_demo_benchmark();
#else
    ui_init();
#endif

    bsp_display_unlock();
}

void app_main(void)
{
    nvs_init();

    encoder_queue_init();

    // liftTube_spillOil_overHeat_init();
    /* Test menu read NVS when first power on */
    // menu_test_for_first_power_on("food_menu_nvs");

    // /* Initialize NTC_thermistor */
    // NTC_thermistor_init();
    Max6675_init();

    // /* Initialize PID calculate */
    PID_calculate_init();

    /* Initialize buzzer */
    buzzer_init();
    // buzzer(NOTE_G4, 0, 0, 0, 0);

    /* Initialize timer mode */
    countdown_init();

    /* Initialize manual mode */
    manual_mode_init();

    // /* Initialize PWM */
    softPwm_t softpwm =
        {
            .PWMPin = 4,
            .freq = 0.2,
        };
    softpwm_init(&softpwm);

    /* Initialize I2C (for touch) */
    bsp_i2c_init();
    /* Initialize display and LVGL */
    bsp_display_start();
    // bsp_display_rotate(bsp_display_start(), LV_DISP_ROT_180);

    /* Turn on display backlight */
    bsp_display_backlight_on();

    /* Add and show objects on display */
    app_lvgl_display();

    // xTaskCreate(memory_monitor_task, "memory_monitor_task", 1024 * 4, NULL, 2, NULL);

    // input_task_create();

#ifndef LVGL_BENCHMARK
    xTaskCreate(UI_task, "UI_task", 1024 * 16, NULL, 2, NULL);
    lv_init();
    lv_port_indev_init();
#endif
    ESP_LOGI(TAG, "Example initialization done.");
}
// *INDENT-ON*

void memory_monitor_task(void *pvParameters)
{
    uint32_t total, used, largest, free_heap;
    while (1)
    {
        total = getHeapSize();
        ESP_LOGI("HEAP INFO", "used heap:%ld", total);

        used = total - xPortGetFreeHeapSize();
        ESP_LOGI("HEAP INFO", "total free heap:%ld", used);

        largest = xPortGetMinimumEverFreeHeapSize();
        ESP_LOGI("HEAP INFO", "largest heap:%ld", largest);

        free_heap = xPortGetFreeHeapSize();
        ESP_LOGI("HEAP INFO", "Free heap:%ld", free_heap);

        vTaskDelay(1000 / portTICK_PERIOD_MS);
    }
}

void NTC_thermistor_update_UI(lv_timer_t *timer)
{
    double temperature =0.0;
    temperature = NTC_thermistor_queue_read();
    // printf("temperature:\n%f\n", temperature);
    if(temperature_unit == Temperature_Unit_Fahrenheit_for_main)
    {
        #if CONFIG_SIMULATED_TEMPERATURE
            //办公室测温
            lv_label_set_text_fmt(ui_LabelSensorTempValue1, "%d°F", (int32_t)(round)((temperature - 173.15) * 1.80 + 32.00)); // Manual Screen Sensor Temperature
            lv_label_set_text_fmt(ui_LabelSensorTempValue, "%d°F", (int32_t)(round)((temperature - 173.15) * 1.80 + 32.00));  // Countdown Screen Sensor Temperature
        #else
            //真实测温
            lv_label_set_text_fmt(ui_LabelSensorTempValue1, "%d°F", (int32_t)(round)((temperature - 273.15) * 1.80 + 32.00)); // Manual Screen Sensor Temperature
            lv_label_set_text_fmt(ui_LabelSensorTempValue, "%d°F", (int32_t)(round)((temperature - 273.15) * 1.80 + 32.00));  // Countdown Screen Sensor Temperature
        #endif        
    }
    else
    {
        #if CONFIG_SIMULATED_TEMPERATURE
            //办公室测温
            lv_label_set_text_fmt(ui_LabelSensorTempValue1, "%d°C", (int32_t)(round)(temperature - 173.15)); // Manual Screen Sensor Temperature
            lv_label_set_text_fmt(ui_LabelSensorTempValue, "%d°C", (int32_t)(round)(temperature - 173.15));  // Countdown Screen Sensor Temperature
        #else
            //真实测温
            lv_label_set_text_fmt(ui_LabelSensorTempValue1, "%d°C", (int32_t)(round)(temperature - 273.15)); // Manual Screen Sensor Temperature
            lv_label_set_text_fmt(ui_LabelSensorTempValue, "%d°C", (int32_t)(round)(temperature - 273.15));  // Countdown Screen Sensor Temperature
        #endif
    }
}

/* manual mode timer */
void manual_mode_countdown_update_UI(lv_timer_t *timer)
{
    enum mode_select_state current_PID_mode = PID_mode_read();
    if (current_PID_mode == mode_manual) 
    {
        if(read_manual_approve_state() == manual_preheat_disapprove) // 无批准倒计时或倒计时时长为0:0的情况
        {
            if(manual_countdown_rest_time_read() <= 0)
            {
                lv_label_set_text_fmt(ui_LabelSensorTempValue2, "%s", _("∞"));
            }
            else
            {
                lv_label_set_text_fmt(ui_LabelSensorTempValue2, "%s", _("Heat")); // 手动剩余时间显示预热
            }    
        }
        else
        {
            if(manual_countdown_time_read() == 0)
            {
                lv_label_set_text_fmt(ui_LabelSensorTempValue2, "%s", _("∞"));
            }
            else
            {
                lv_label_set_text_fmt(ui_LabelSensorTempValue2, _("%d:%d"), manual_countdown_rest_time_minute(manual_countdown_rest_time_read()), manual_countdown_rest_time_second(manual_countdown_rest_time_read())); // 显示手动操作设定时间    
            }    
            if(read_manual_drop_approve() == manual_drop_disapprove)
            {
                // write_manual_drop_approve(manual_drop_wait_approve);
                // buzzer_occasion_queue_write(buzzer_drop_approve);
            }
        }
    }
    else 
    {
        // write_manual_drop_approve(manual_preheat_disapprove);
        // 显示手动操作倒计时总时长
        lv_label_set_text_fmt(ui_LabelSensorTempValue2, _("%d:%d"), (manual_countdown_time_read()/60), (manual_countdown_time_read()%60)); // 显示手动操作操作倒计时剩余时间    
        lv_obj_whether_ban_animation(ui_BarManualTemperature1, 0);
    }
}

uint32_t getHeapSize(void)
{
    multi_heap_info_t info;
    heap_caps_get_info(&info, MALLOC_CAP_INTERNAL);
    return info.total_free_bytes + info.total_allocated_bytes;
}

void my_ScreenAuto_cb(lv_event_t *e)
{
    lv_event_code_t event_code = lv_event_get_code(e);
    if(event_code == LV_EVENT_SCREEN_LOADED) {
        current_screen_load = Auto_Loaded;
    }
}

void my_ScreenManual_cb(lv_event_t *e)
{
    lv_event_code_t event_code = lv_event_get_code(e);
    if(event_code == LV_EVENT_SCREEN_LOADED) {
        current_screen_load = Manual_Loaded;
    }
}

void my_ScreenSetting_cb(lv_event_t *e)
{
    lv_event_code_t event_code = lv_event_get_code(e);
    if(event_code == LV_EVENT_SCREEN_LOADED) {
        current_screen_load = Setting_Loaded;
    }
}

void set_language_by_nvs_for_power_on()
{
    // Set language
    lv_i18n_init(lv_i18n_language_pack);
    char *current_locate_language = "en";
	// char *current_locate_full_language = "English";
    uint16_t current_locate_selected_option = 0;
	if(nvs_read_str("locale_name", &current_locate_language) != ESP_OK)
	{
		current_locate_language = "en";
		nvs_write_str("locale_name", current_locate_language);
	}
	if (strcmp(current_locate_language, "zh-hk") == 0) {
        current_locate_selected_option = 1;
    } else if (strcmp(current_locate_language, "zh-cn") == 0) {
        current_locate_selected_option = 2;
    } else if (strcmp(current_locate_language, "en") == 0) {
        current_locate_selected_option = 0;
    }else if (strcmp(current_locate_language, "es") == 0) {
        current_locate_selected_option = 3;
    }else if (strcmp(current_locate_language, "fr") == 0) {
        current_locate_selected_option = 4;
    }else if (strcmp(current_locate_language, "id") == 0) {
        current_locate_selected_option = 5;
    }
    
    lv_i18n_set_locale(current_locate_language);
    refresh_lv_i18n_label_text();
    lv_roller_set_selected(ui_Roller2, current_locate_selected_option, LV_ANIM_ON);
    free(current_locate_language);
}

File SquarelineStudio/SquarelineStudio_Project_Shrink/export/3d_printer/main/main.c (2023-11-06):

/*
 * SPDX-FileCopyrightText: 2022 Espressif Systems (Shanghai) CO LTD
 *
 * SPDX-License-Identifier: CC0-1.0
 */

#include "esp_log.h"
#include "bsp/ws_7inch.h"
#include "lvgl.h"
#include "ui/ui.h"


#define TAG "ESP-EXAMPLE"

/*******************************************************************************
* Private functions
*******************************************************************************/

// *INDENT-OFF*
void app_lvgl_display(void)
{
    bsp_display_lock(0);

    ui_init();

    bsp_display_unlock();
}

void app_main(void)
{
    /* Initialize I2C (for touch) */
    bsp_i2c_init();

    /* Initialize display and LVGL */
    bsp_display_start();

    /* Turn on display backlight */
    bsp_display_backlight_on();

    /* Add and show objects on display */
    app_lvgl_display();

    ESP_LOGI(TAG, "Example initialization done.");
}
// *INDENT-ON*

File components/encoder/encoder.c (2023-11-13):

#include "encoder.h"

static rotary_encoder_t *encoder = NULL; /* 编码器 */
static SemaphoreHandle_t mutex = NULL;

static int32_t encoder_diff = 0;          /* 编码器转动方向，0为静止，1为顺时针旋转，-1为逆时针旋转 */
static bool encoder_diff_disable = false; /* 获取编码器数值，true为使能，false为失能 */
int32_t cnt;

QueueHandle_t Encoder_Mailbox;
QueueHandle_t Handle_Queue_Manual_Target_temperature;
// QueueHandle_t Handle_Mode_Change;

key_state_t encoder_push_state;

/* 编码器配置 */
void encoder_config(void)
{
    uint32_t pcnt_unit = 0;

    mutex = xSemaphoreCreateMutex();

    /* 1.配置编码器KEY GPIO */
    gpio_config_t io_conf = {
        .intr_type = GPIO_INTR_DISABLE,
        // .pin_bit_mask = ENCODER_PUSH_GPIO_PIN_SEL,
        .mode = GPIO_MODE_INPUT,
        .pull_down_en = 0, /* 允许下拉 */
        .pull_up_en = 1,
    };

    gpio_config(&io_conf);

    /* 2.配置编码器A、B */
    rotary_encoder_config_t config = ROTARY_ENCODER_DEFAULT_CONFIG((rotary_encoder_dev_t)pcnt_unit, ENCODER_A_PIN, ENCODER_B_PIN);
    ESP_ERROR_CHECK(rotary_encoder_new_ec11(&config, &encoder));
    ESP_ERROR_CHECK(encoder->set_glitch_filter(encoder, 10)); /* 滤波器 */
    ESP_ERROR_CHECK(encoder->start(encoder));
}

// static key_state_t encoder_push_scan(void)
// {
//     if (gpio_get_level(ENCODER_PUSH_PIN) == 0)
//     {
//         vTaskDelay(pdMS_TO_TICKS(20));
//         if (gpio_get_level(ENCODER_PUSH_PIN) == 0)
//         {
//             return KEY_DOWN;
//         }
//     }

//     return KEY_UP;
// }

void encoder_queue_init()
{
    Encoder_Mailbox = xQueueCreate(1, sizeof(uint));
    // Handle_Mode_Change = xQueueCreate(1, sizeof(button_mode_t));
    Handle_Queue_Manual_Target_temperature = xQueueCreate(1, sizeof(long));
}

/**
 * @brief Task for handling the encoder operations.
 *
 * This task handles the encoder operations by periodically checking the encoder state,
 * detecting key presses and direction changes, and performing corresponding actions.
 * It utilizes a mutex for synchronization and interacts with the HC165 shift register
 * for reading the encoder values. It also writes data to various mailboxes and updates
 * the mode change button state.
 *
 * @param pvParameter The task parameter (not used).
 * @return None.
 */
static void encoder_task(void *pvParameter)
{
    uint8_t key = 0;
    // HC165_encoder_pin.dataPin = 5;
    
    // button_mode_t state_mode_change = BUTTON_AUTO_READY_MODE;
    // Mode_change_button_write(state_mode_change);
    
    while (1)
    {
        vTaskDelay(pdMS_TO_TICKS(150));
        if (pdTRUE == xSemaphoreTake(mutex, portMAX_DELAY))
        {
            /* 1.KEY检测 */
            // encoder_push_state = encoder_push_scan();
            // ESP_LOGI("ESP", "encoder_push_state = %d\n",encoder_push_state);

            /* 2.方向检测 */
            // if (!encoder_diff_disable)
            // {
                // 旋钮操作
                cnt = encoder->get_counter_value(encoder) / 8; /* 获取编码器数值 */
                // printf("cnt = %d\n", cnt);
                // ESP_LOGI("ESP", "cnt = %d\n", cnt);
                Encoder_queue_write(cnt);
                xSemaphoreGive(mutex);
        }
    }
}

void input_task_create(void)
{
    xTaskCreatePinnedToCore(encoder_task, "input task", 1024*8, NULL, 1, NULL, 1);
}

int Encoder_queue_read(void)
{
    int cnt = 0;
    xQueuePeek(Encoder_Mailbox, &cnt, 0);
    return cnt;
}

void Encoder_queue_write(int cnt)
{
    xQueueOverwrite(Encoder_Mailbox, &cnt);
}

int32_t encoder_get_diff(void)
{
    int32_t diff = cnt;
    return diff;
}

bool encoder_get_is_push(void)
{
    /* 编码器KEY按下不再读取方向数值 */
    if (encoder_push_state == KEY_DOWN)
    {
        encoder_diff_disable = true;
        return true;
    }
    else
    {
        encoder_diff_disable = false;
        return false;
    }
}

long Encoder_temperature_queue_read(void)
{
    long current_temperature = 0;
    xQueuePeek(Handle_Queue_Manual_Target_temperature, &current_temperature, 0);
    return current_temperature;
}

void Encoder_temperature_queue_write(long current_temperature)
{
    xQueueOverwrite(Handle_Queue_Manual_Target_temperature, &current_temperature);
}

// button_mode_t Mode_change_button_read(void)
// {
//     button_mode_t current_mode = BUTTON_MANUAL_MODE;
//     xQueuePeek(Handle_Mode_Change, &current_mode, 0);
//     return current_mode;
// }

// void Mode_change_button_write(button_mode_t current_mode)
// {
//     xQueueOverwrite(Handle_Mode_Change, &current_mode);
// }

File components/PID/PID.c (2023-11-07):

#include <PID.h>

QueueHandle_t handle_queue_PID;
QueueHandle_t handle_queue_PID_set_temperature;
QueueHandle_t handle_queue_PID_mode_state;

PID_structure pid_set;

double PWM_var = 0; // 占空比
double dError = 0;
double Error = 0;
double SumError = 0;
double now_temperature = 0;
double PrevError = 0;
/*
 PID 计算
 */

void PID_calculate_init() // 不改变比例、积分、微分常数、死区，第一次读取到的值赋予所有偏差
{
    pid_set.SetTemperature = 449.82;                      // 默认鸡块油温(K)
    // pid_set.SetTemperature = 180;                       // 默认鸡块油温
    pid_set.Proportion = (double)Proportion_Coefficient;        // 比例常数
    pid_set.Integral = (double)Integral_Coefficient;            // 积分常数
    pid_set.Derivative = (double)Derivative_Coefficient;        // 微分常数
    pid_set.umin = pid_set.SetTemperature - Umin_range; // 死区
    pid_set.FirstError = 1;                             // The number is not important. Init only. Do not use 0.
    pid_set.LastError = pid_set.FirstError;
    pid_set.PrevError = pid_set.FirstError;
    pid_set.SumError = pid_set.FirstError;

    PID_queue_init();
    PID_set_temperature_write(pid_set.SetTemperature); // 队列里写入默认设定温度

    xTaskCreate(task_pid_calculate, "PIDCalculateTask", 1024 * 4, NULL, 2, NULL);
}

void task_pid_calculate(void *ptr) // 融化参数
{
    
    // int cooking_time_remaining = 0; // 倒计时剩余时间

    while (1)
    {
        // double SumError;
        enum mode_select_state current_PID_mode = PID_mode_read();

        pid_set.SetTemperature = PID_set_temperature_read() - 273.15; //kelvin to celsius
        // printf("%.2f\n",pid_set.SetTemperature);
        pid_set.umin = pid_set.SetTemperature - Umin_range;
        // ESP_LOGI("Set Temperature", "target Temperature celsius = %.2f°C", pid_set.SetTemperature);

        #if CONFIG_SIMULATED_TEMPERATURE
			now_temperature = NTC_thermistor_queue_read() - 173.15; // 办公室测温
        #else
			now_temperature = NTC_thermistor_queue_read() - 273.15; // 真实测温
            // now_temperature = 200;
		#endif

        // ESP_LOGI("Now Temperature", "now Temperature = %.2f°C", now_temperature); //kelvin to celsius
        Error = pid_set.SetTemperature - now_temperature; // 先计算偏差
        
        // printf("SumError:%.2f\n",SumError);  
        
        if (isnan(Error))
        {
            SumError = 0;
        }
        else
        {
            SumError = SumError + Error;
        }
        
        if ((SumError >= SumError_threshold) || (now_temperature <= pid_set.SetTemperature - 2))
        {
            SumError = SumError_threshold;
        }
        if (SumError <= -SumError_threshold)
        {
            SumError = (-1)*SumError_threshold;
        }
        // printf("Error:%.2f\n",Error);
        // printf("SumError:%.2f\n",SumError);
        
        dError = Error - PrevError; // 对偏差微分
        PrevError = Error;
        // printf("dError:%.2f\n",dError);
        if ((current_PID_mode == mode_timer) || (current_PID_mode == mode_manual))
        {
            if(now_temperature > pid_set.SetTemperature)
            {
                PWM_var = Duty_MIN;
            }
            else if(now_temperature <= pid_set.SetTemperature - 5)
            {
                PWM_var = Duty_MAX;
            }  
        }
        if ((now_temperature > pid_set.SetTemperature) || (current_PID_mode == mode_null))
        {
            PWM_var = Duty_MIN;
            // ESP_LOGI("Set Temperature", "Countdown stop\n");
        }
        
        if (PWM_var >= Duty_MAX)
        {
            PWM_var = Duty_MAX;
        }
        else if (PWM_var <= Duty_MIN)
        {
            PWM_var = Duty_MIN;
        }
        PID_queue_write(PWM_var);
        // ESP_LOGI("PWM_var", "PWM_var = %.2f%%", (float) PWM_var/255*100);
        vTaskDelay(1000 / portTICK_PERIOD_MS);
    }
}

// API接口
esp_err_t PID_queue_init()
{
    handle_queue_PID = xQueueCreate(1, sizeof(int));
    handle_queue_PID_set_temperature = xQueueCreate(1, sizeof(double));
    handle_queue_PID_mode_state = xQueueCreate(1, sizeof(enum mode_select_state));
    return ESP_OK;
}

// read
int PID_queue_read(void)
{
    int current_duty = 0;
    xQueuePeek(handle_queue_PID, &current_duty, 1);
    return current_duty;
}

// write
esp_err_t PID_queue_write(int duty)
{
    xQueueOverwrite(handle_queue_PID, &duty);
    return ESP_OK;
}

double PID_set_temperature_read(void)
{
    double set_temperature = 0;
    xQueuePeek(handle_queue_PID_set_temperature, &set_temperature, 1);
    return set_temperature;
}

esp_err_t PID_set_temperature_write(double set_temperature)
{
    xQueueOverwrite(handle_queue_PID_set_temperature, &set_temperature);
    return ESP_OK;
}

enum mode_select_state PID_mode_read(void)
{
    enum mode_select_state current_PID_mode = mode_null;
    xQueuePeek(handle_queue_PID_mode_state, &current_PID_mode, 1);
    return current_PID_mode;
}

esp_err_t PID_mode_write(enum mode_select_state mode_state)
{
    xQueueOverwrite(handle_queue_PID_mode_state, &mode_state);
    return ESP_OK;
}

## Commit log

2023-11-06 添加扒炉代码
    版本号为1.0.1
    [partitions.csv, v2.1.1.PcbDoc, v2.2.0.PcbDoc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]
2023-11-07 移除8575组件，注释旋钮任务
    该版本号为1.0.2
2023-11-07 上传max6675代码
2023-11-11 移除掉不需要的组件
2023-11-11 蜂鸣器、旋钮引脚空出给max6675使用
2023-11-11 加入max6675组件，对测温的相关代码进行改动
    改版本号为“1.1.0”
2023-11-13 将ui上的校准改成-25~25
    版本号改为1.1.1
2023-11-13 添加滑条event,TemperatureCalibrationSlider(e)。
2023-11-17 添加变压器等的相关文档
2023-11-17 添加热电偶、热敏电阻的测试报告
2023-11-17 添加温度校准功能
    更新版本为“1.2.0”
    具体功能：
    1. 修改温度校准滑条和温度校准使能
    2. 温度校准使能可以用于将滑条数据添加到NVS
    3. 可实现一上电就能根据NVS读取的校准值来改变滑条和当前温度
2023-11-25 添加通用版的屏幕引脚配置
2023-11-25 初始化时去除显示左右升降机标识
2023-11-25 针对以上修改，该版本号为“1.2.1”
2023-11-27 将扒炉初始化时的温度单位改成摄氏度
    将版本号改为“1.2.2”
2023-11-27 将手动模式页面初始化的温度单位改为摄氏度，使自动模式不可选
    版本号改为“1.2.3”
2023-11-27 将设置页面的无效按键不可选，自动操作页面不可选
    该版本号为“1.2.4”
2024-01-16 添加浪涌抑制器的选用理由及相关测试数据、时间表
    [扒炉(2).xlsx]
2024-01-16 将max6675模块的MDIO引脚改成1号脚
2024-01-16 添加蜂鸣器功能，将蜂鸣器脚改为14脚
    版本号为“1.2.5”
2024-01-16 将预热达到目标温度-2触发倒计时改为达到-20就可触发倒计时
    该版本号为“1.2.6”
